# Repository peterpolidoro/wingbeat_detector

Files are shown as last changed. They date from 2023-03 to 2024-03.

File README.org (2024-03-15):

# This file is generated automatically from metadata
# File edits may be overwritten!
- Project Name: wingbeat_detector
- Synopsis: Measures fly wingbeats using IR light reflected from flapping fly wings.
- Documentation Version: 4.0.0
- Pcb Version: 4.0
- Enclosure Version: 1.1
- Supplemental BOM Version: 1.0
- Release Date: 2024-03-14
- Creation Date: 2023-02-17
- Kicad Version: 7.0.11
- License: GPL-3.0
- URL: https://github.com/peterpolidoro/wingbeat_detector
- Author: Peter Polidoro
- Email: peter@polidoro.io
- Copyright: 2024 Peter Polidoro
- References:
  - [[https://www.kicad.org/][kicad]]
  - [[https://github.com/janelia-kicad/light_sensor_boards][light_sensor_boards]]
- Papers:
  - [[https://doi.org/10.1016/j.cub.2023.01.020][Active antennal movements in Drosophila can tune wind encoding]]
  - [[https://doi.org/10.1016/j.jneumeth.2018.04.019][A novel assay to evaluate action selection in escape behavior]]
  - [[https://doi.org/10.1038/nn.4083][Cellular evidence for efference copy in Drosophila visuomotor processing]]
  - [[https://doi.org/10.1038/s41593-019-0413-4][State-dependent decoupling of sensory and motor circuits underlies behavioral flexibility in Drosophila]]
  - [[https://doi.org/10.1038/nn.2492][Active flight increases the gain of visual motion processing in Drosophila]]
  - [[https://doi.org/10.1242/jeb.82.1.377][An Optical Tachometer for Measurement of the Wing-Beat Frequency of Free-Flying Insects]]

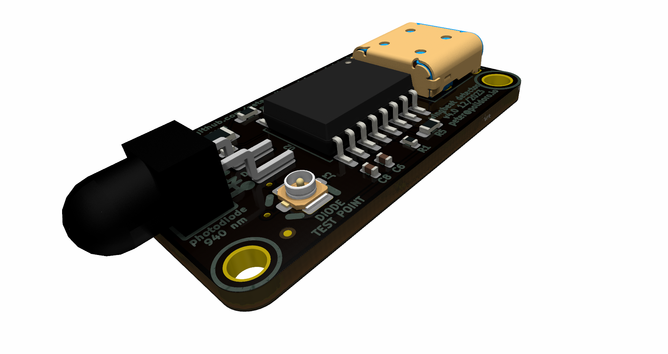
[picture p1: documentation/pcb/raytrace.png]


This wingbeat detector, or flight “tachometer”, is a small electro-optical
device that uses reflected infrared light from the fly’s wingbeats to generate
an oscillating voltage signal. The oscillation frequency of the voltage signal
matches, and thus allows one to measure, the tethered fly's wingbeat frequency.

This device is useful for plate (rather than pin) tethered flight experiments,
because with plate-glued flies, one cannot extract the wingbeat frequency via a
classical wingbeat analyzer. Microphones have also been used for extracting
wingbeat frequency, but they require a quiet room. This wingbeat detector is
immune to audible noise and only requires an infrared light source, often
already present on flight rigs for video recording.

One end of a small diameter light guide is mounted near the fly and aimed at the
wings. The other end of the light guide is in a small enclosure containing an
optical filter and printed circuit board and can be mounted off to the side of
the rig wherever there is room.

The light guide brings light reflected off of the wings down to a photodiode on
a circuit board, after passing through an optical filter to remove the unwanted
wavelengths of light. Amplifiers and filters on the circuit board convert the
tiny amounts of current from the photodiode into an oscillating voltage signal,
with a frequency range of several hundred Hertz and a magnitude range of several
Volts.

The oscillating voltage signal can be fed into a data acquisition card,
oscilloscope, and/or a speaker for recording and instant feedback on fly
wingbeat frequency. Using a threshold, the signal can be used as a simple
boolean that indicates whether the tethered animal is flying or not for
triggering experiments or synchronizing the data collection.

This device was first created at Caltech in the Dickinson lab in collaboration
with Gaby Maimon around 2010. It has transformed over several generations,
getting smaller and more robust each iteration. It has been used on rigs in
multiple universities and research institutes and has been referenced in several
papers. A couple of iterations were designed in collaboration with Sung Soo Kim
and the Card lab at Janelia Research Campus. The latest version was created in
collaboration with the Suver lab at Vanderbilt.

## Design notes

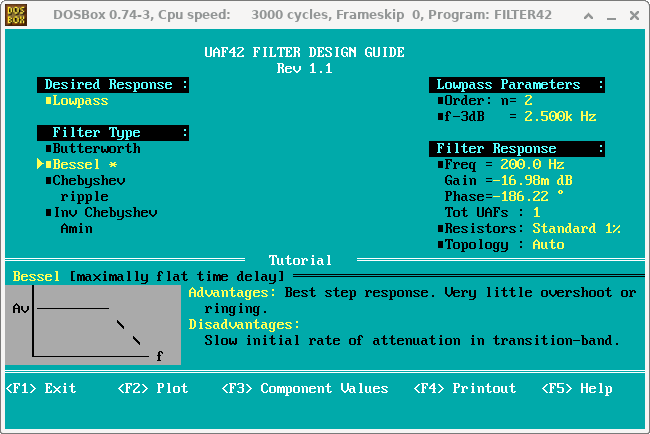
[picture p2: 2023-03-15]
documentation/filter/low-pass-filter-design.png

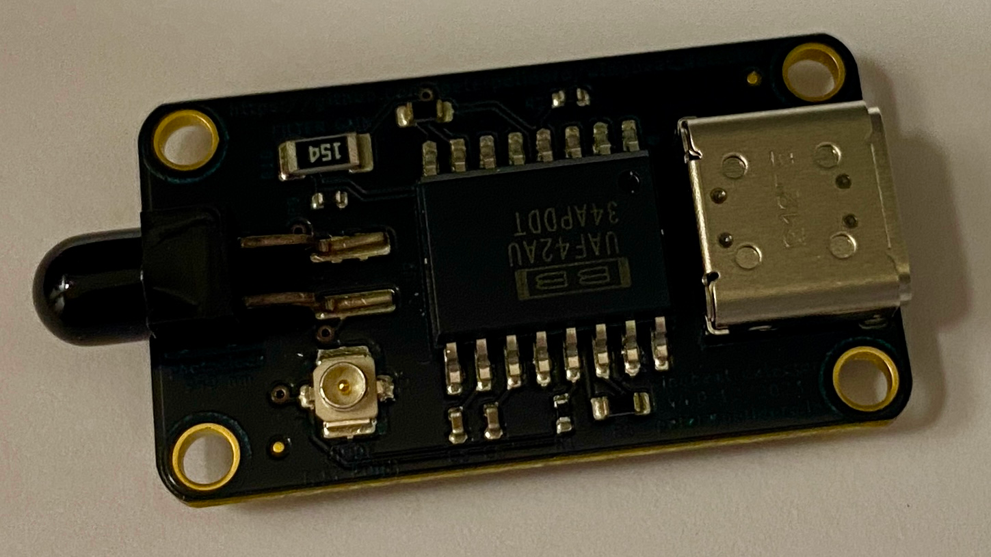
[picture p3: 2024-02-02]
documentation/photos/wingbeat_detector_photo_3.png

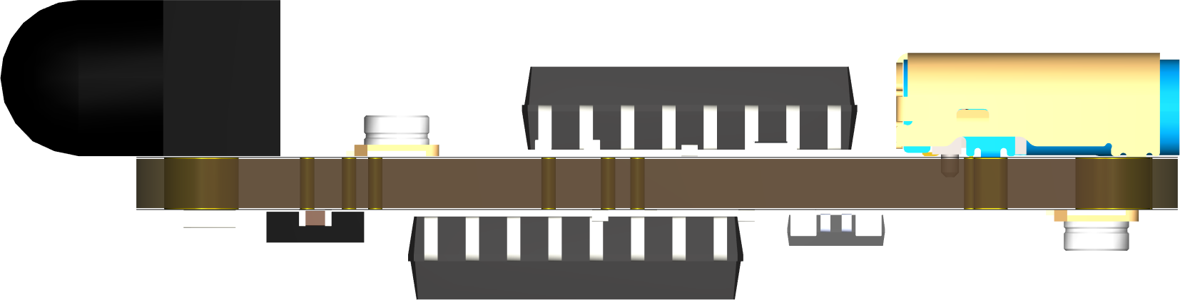
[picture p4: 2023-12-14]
documentation/pcb/front.png

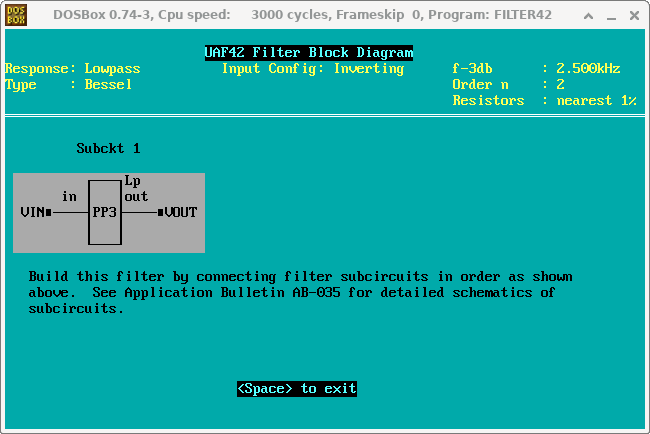
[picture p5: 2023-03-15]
documentation/filter/low-pass-filter-block-diagram.png

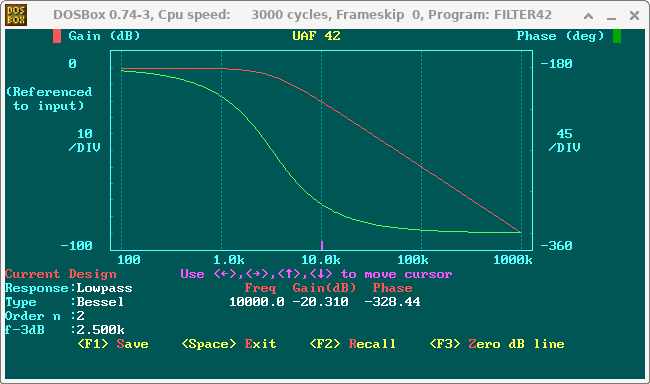
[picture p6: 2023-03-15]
documentation/filter/low-pass-filter-plot.png

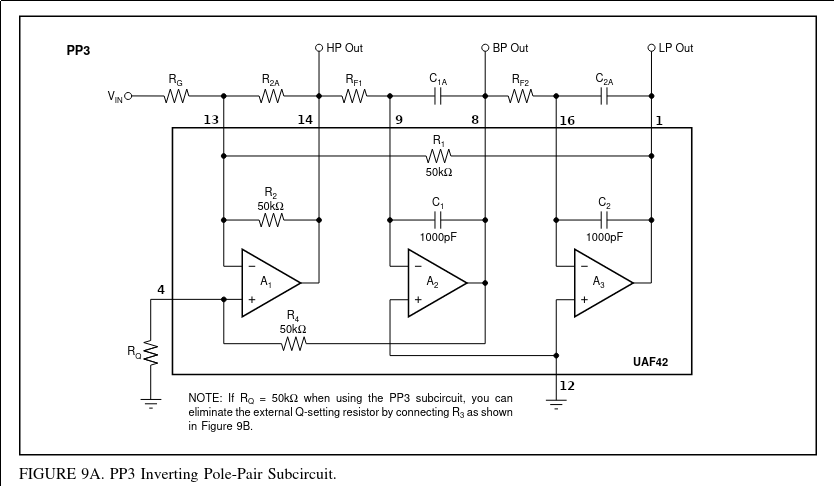
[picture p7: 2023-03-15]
documentation/filter/pp3.png

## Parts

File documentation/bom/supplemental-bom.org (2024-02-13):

#+OPTIONS: toc:nil title:nil num:nil ^:nil
#+LATEX_HEADER: \usepackage{adjustbox}
#+LATEX_HEADER: \usepackage[margin=2cm]{geometry}
* Supplemental BOM
- Project Name: wingbeat_detector
- Synopsis: Measures fly wingbeats using IR light reflected from flapping fly wings.
- Release Date: 2024-02-13
- URL: https://github.com/peterpolidoro/wingbeat_detector
- Author: Peter Polidoro
- Email: peter@polidoro.io
#+BEGIN_TABLE
#+LATEX: \adjustbox{max width=\linewidth}{
#+ATTR_LATEX: :center nil
| Item | Description                                            | Manufacturer Part Number | Manufacturer        | Quantity |   Cost |   Total |
|------+--------------------------------------------------------+--------------------------+---------------------+----------+--------+---------|
|    1 | BNC STRAIGHT BULKHEAD JACK TO AM                       | 095-850-210-150          | Amphenol RF         |        1 |  24.41 |   24.41 |
|    2 | AC/DC WALL MNT ADAPTER 5.1V 15W                        | SC0445                   | Raspberry Pi        |        1 |   8.00 |    8.00 |
|    3 | CBL ASSY BNC PLUG-PLUG RG58 5'                         | 5697-60                  | Pomona Electronics  |        1 |  21.29 |   21.29 |
|    4 | LLG 3 mm Core 420 - 2000 nm 1.2 m                      | LLG3-4Z                  | thorlabs            |        1 | 392.69 |  392.69 |
|    5 | 3 mm LLG to SM1 Adapter                                | AD3LLG                   | thorlabs            |        1 |  38.32 |   38.32 |
|    6 | Adapter External SM05 Internal SM1                     | SM1A1                    | thorlabs            |        1 |  23.41 |   23.41 |
|    7 | SM05 Adjustable Lens Tube                              | SM05V05                  | thorlabs            |        1 |  31.64 |   31.64 |
|    8 | 825nm 12.5mm Dia Longpass Filter                       | 86-062                   | edmundoptics        |        1 | 194.00 |  194.00 |
|    9 | Universal probe holder                                 | MXB                      | siskiyou            |        1 | 275.00 |  275.00 |
|   10 | MACHINE SCREW PAN PHILLIPS 2-56                        | PMSSS 256 0050 PH        | B&F Fastener Supply |        4 |   0.24 |    0.96 |
|   11 | HEX NUT 3/16" STN STEEL 2-56                           | HNSS256                  | B&F Fastener Supply |        4 |   0.28 |    1.12 |
|------+--------------------------------------------------------+--------------------------+---------------------+----------+--------+---------|
|      | Supplemental BOM Version: 1.0 |                          |                     |          |  Total | 1010.84 |
#+TBLFM: $7=$5*$6;%0.2f::@>$7=vsum(@2..@-1);%0.2f
#+LATEX: }
#+END_TABLE

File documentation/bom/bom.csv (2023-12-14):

Item | Reference(s) | Quantity | Manufacturer | Manufacturer Part Number | Vendor | Vendor Part Number | Description | Package
1 | C1 C2 C3 C4 C5 | 5 | TDK Corporation | C1608X5R1C475K080AC | Digi-Key | 445-7478-1-ND | CAP CER 4.7UF 16V X5R 0603
2 | C6 C7 C8 C9 | 4 | Yageo | CC0402ZRY5V8BB104 | Digi-Key | 311-1375-1-ND | CAP CER 0.1UF 25V Y5V | 0402
3 | C10 | 1 | Samsung Electro-Mechanics | CL05A105KL5NRNC | Digi-Key | 1276-6796-1-ND | CAP CER 1UF 35V X5R | 0402
4 | C11 | 1 | KEMET | C0402C300J5GACAUTO | Digi-Key | 399-C0402C300J5GACAUTOCT-ND | CAP CER 30PF 50V C0G/NP0 | 0402
5 | D1 | 1 | American Bright Optoelectronics Corporation | BPD-BQDA38V-FZ04 | Digi-Key | BPD-BQDA38V-FZ04CT-ND | SENSOR PHOTODIODE RADIAL
6 | J1 | 1 | Amphenol | 10137062-00021LF | Digi-Key | 609-6109-1-ND | CONN RCP USB3.1 TYPEC 24P SMD RA
7 | J2 J3 | 2 | Amphenol RF | A-1JB | Digi-Key | 115-A-1JBCT-ND | CONN UMC JACK STR 50 OHM SMD
8 | R1 R3 R6 R8 | 4 | Panasonic Electronic Components | ERJ-2RKF4992X | Digi-Key | P49.9KLCT-ND | RES SMD 49.9K OHM 1% 1/10W | 0402
9 | R2 R4 | 2 | Panasonic Electronic Components | ERJ-2RKF6812X | Digi-Key | P68.1KLCT-ND | RES SMD 68.1K OHM 1% 1/10W | 0402
10 | R5 R7 | 2 | Vishay Dale | CRCW06033M65FKEA | Digi-Key | 541-3.65MHCT-ND | RES SMD 3.65M OHM 1% 1/10W | 0603
11 | R9 | 1 | Panasonic Electronic Components | ERJ-2RKF2490X | Digi-Key | P249LCT-ND | RES SMD 249 OHM 1% 1/10W | 0402
12 | R10 | 1 | Panasonic Electronic Components | ERA-8AEB154V | Digi-Key | P150KBCCT-ND | RES SMD 150K OHM 0.1% 1/4W | 1206
13 | R11 | 1 | Panasonic Electronic Components | ERJ-PM8F2004V | Digi-Key | 10-ERJ-PM8F2004VCT-ND | RES 2.0M OHM 1% 0.66W | 1206
14 | U1 | 1 | Maxim Integrated | MAX865EUA+ | Digi-Key | MAX865EUA+-ND | IC REG CHARGE PUMP INV DL 8UMAX | SOP65P490X110-8N
15 | U2 U3 | 2 | Texas Instruments | UAF42AU | Digi-Key | UAF42AU-ND | IC UNIV ACTIVE FILTER 16-SOIC
16 | U4 | 1 | Texas Instruments | OPA381AIDRBT | Digi-Key | 296-17363-1-ND | IC TRANSIMPEDANCE 1 CIRCUIT 8SON

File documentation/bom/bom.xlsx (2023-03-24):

Item | Reference(s) | Quantity | Manufacturer | Manufacturer Part Number | Vendor | Vendor Part Number | Description | Package
1 | C1 C2 C3 C4 C5 C13 | 6 | TDK Corporation | C1608X5R1C475K080AC | Digi-Key | 445-7478-1-ND | CAP CER 4.7UF 16V X5R 0603
2 | C6 C7 C8 C9 C10 C12 | 6 | Yageo | CC0402ZRY5V8BB104 | Digi-Key | 311-1375-1-ND | CAP CER 0.1UF 25V Y5V | 402
3 | C11 | 1 | TDK Corporation | CGA2B2C0G1H020C050BA | Digi-Key | 445-5572-1-ND | CAP CER 2PF 50V C0G | 402
4 | D1 | 1 | American Bright Optoelectronics Corporation | BPD-BQDA38V-FZ04 | Digi-Key | BPD-BQDA38V-FZ04CT-ND | SENSOR PHOTODIODE RADIAL
5 | D2 | 1 | American Bright Optoelectronics Corporation | BIR-BM17J8V-FZ04 | Digi-Key | BIR-BM17J8V-FZ04CT-ND | 5MM 940 IR
6 | J1 | 1 | Amphenol | 10137062-00021LF | Digi-Key | 609-6109-1-ND | CONN RCP USB3.1 TYPEC 24P SMD RA
7 | J2 J3 J4 | 3 | Amphenol RF | A-1JB | Digi-Key | 115-A-1JBCT-ND | CONN UMC JACK STR 50 OHM SMD
8 | Q1 | 1 | Texas Instruments | CSD17483F4 | Digi-Key | 296-38914-1-ND | MOSFET N-CH 30V 1.5A 3PICOSTAR
9 | R1 R3 R6 R8 R10 R11 R12 R14 R16 | 9 | Panasonic Electronic Components | ERJ-2RKF4992X | Digi-Key | P49.9KLCT-ND | RES SMD 49.9K OHM 1% 1/10W | 402
10 | R2 R4 | 2 | Panasonic Electronic Components | ERJ-2RKF6812X | Digi-Key | P68.1KLCT-ND | RES SMD 68.1K OHM 1% 1/10W | 402
11 | R5 R7 | 2 | Vishay Dale | CRCW06033M65FKEA | Digi-Key | 541-3.65MHCT-ND | RES SMD 3.65M OHM 1% 1/10W | 603
12 | R9 | 1 | Panasonic Electronic Components | ERJ-2RKF2490X | Digi-Key | P249LCT-ND | RES SMD 249 OHM 1% 1/10W | 402
13 | R13 R15 | 2 | Panasonic Electronic Components | ERJ-2RKF2322X | Digi-Key | P23.2KLCT-ND | RES SMD 23.2K OHM 1% 1/10W | 402
14 | R17 | 1 | Panasonic Electronic Components | ERJ-2RKF2001X | Digi-Key | P2.00KLCT-ND | RES SMD 2K OHM 1% 1/10W | 402
15 | RV1 RV2 | 2 | Bourns Inc. | 3223W-1-504E | Digi-Key | 3223W-1-504ECT-ND | TRIMMER 500K OHM 0.125W J LEAD
16 | U1 | 1 | Maxim Integrated | MAX865EUA+ | Digi-Key | MAX865EUA+-ND | IC REG CHARGE PUMP INV DL 8UMAX | SOP65P490X110-8N
17 | U2 U3 | 2 | Texas Instruments | UAF42AU | Digi-Key | UAF42AU-ND | IC UNIV ACTIVE FILTER 16-SOIC
18 | U4 | 1 | Texas Instruments | OPA381AIDRBT | Digi-Key | 296-17363-1-ND | IC TRANSIMPEDANCE 1 CIRCUIT 8SON
19 | U5 | 1 | STMicroelectronics | TSV630IQ1T | Digi-Key | 497-17045-1-ND | IC OPAMP GP 1 CIRCUIT | 6DFN
20 | U6 | 1 | American Bright Optoelectronics Corporation | AB-EZPC-10 | Digi-Key | AB-EZPC-10CT-ND | IC LED DRIVER LINEAR 50MA | 6DFN

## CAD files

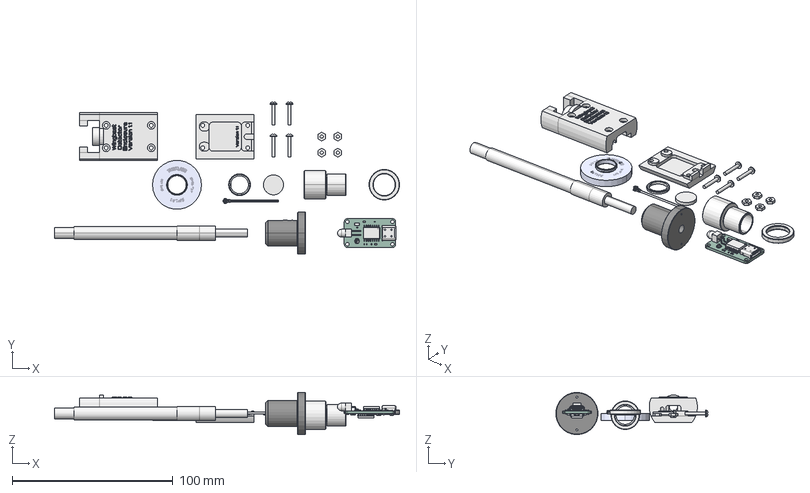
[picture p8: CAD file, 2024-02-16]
documentation/3dmodels/freecad/documentation.FCStd
214.6 x 94.6 x 26.3 mm
wingbeat_detector PCB
enclosure-top001
enclosure-bottom001
screw001
screw002
screw003
screw004
nut001
nut002
nut003
nut004
tube001
tube-nut001
lens-nut
ֱ2_86062
1691-E0W

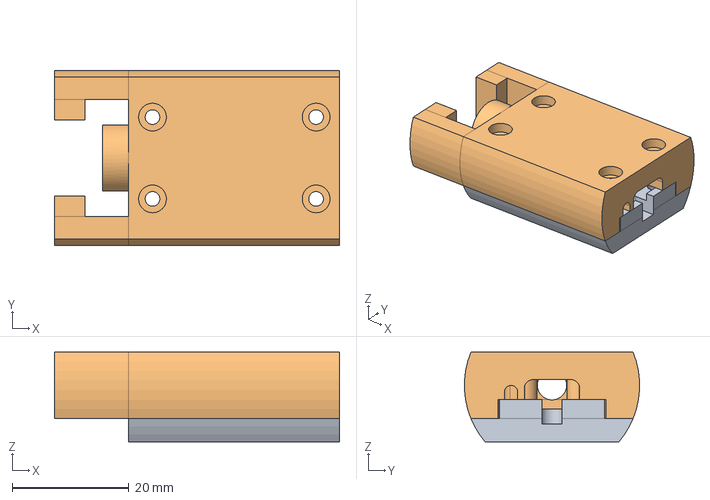
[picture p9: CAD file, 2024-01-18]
documentation/3dmodels/freecad/wingbeat_detector.FCStd
48.8 x 30.0 x 15.3 mm
enclosure-bottom001
enclosure-top001

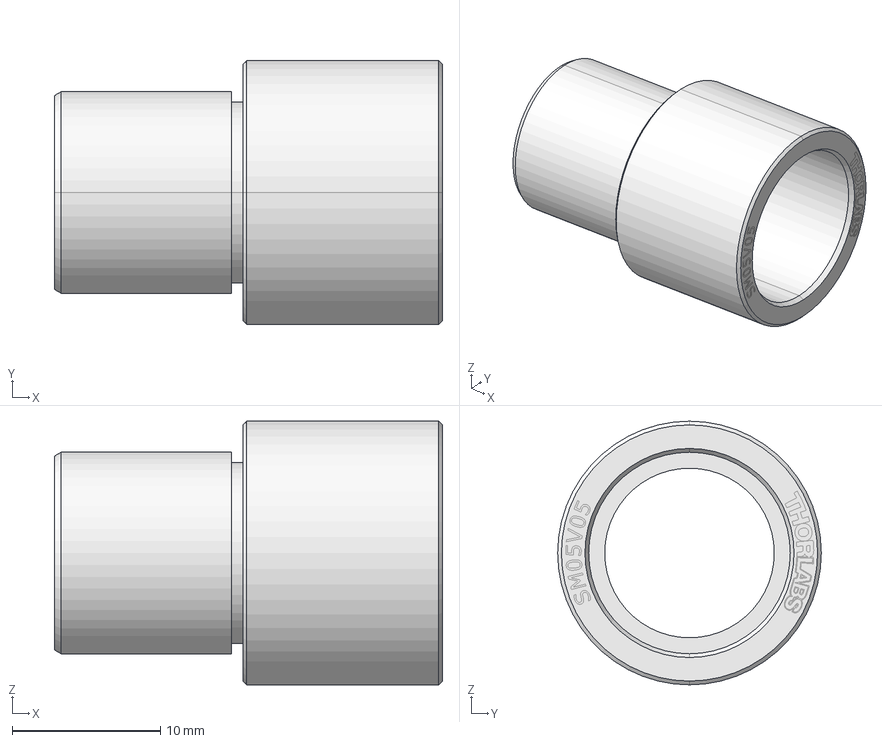
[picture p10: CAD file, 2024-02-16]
documentation/3dmodels/step/tube.step
26.2 x 17.8 x 17.8 mm

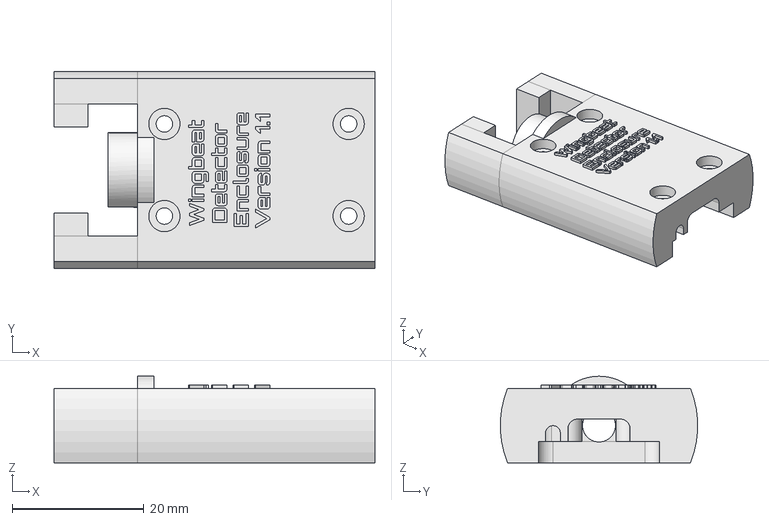
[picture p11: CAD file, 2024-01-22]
documentation/3dmodels/step/wingbeat-detector-enclosure-top.step
48.8 x 30.0 x 13.2 mm

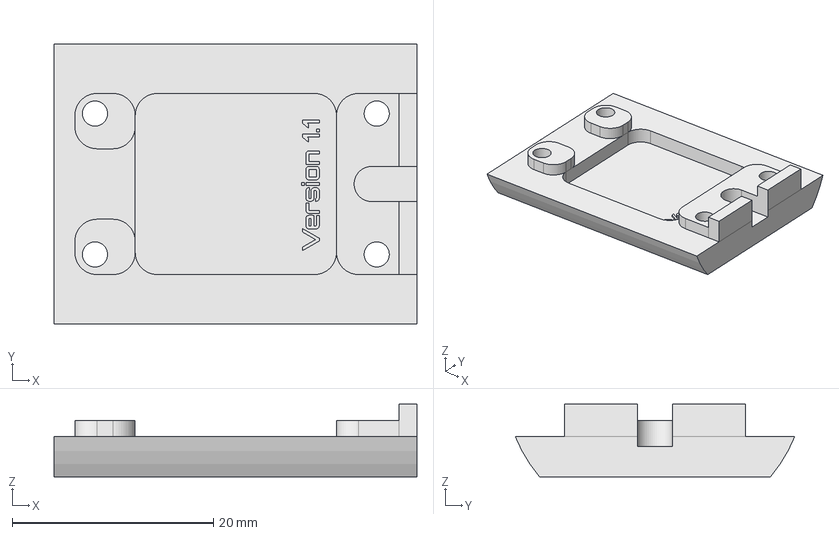
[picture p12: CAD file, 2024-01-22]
documentation/3dmodels/step/wingbeat-detector-enclosure-bottom.step
36.1 x 27.8 x 7.21 mm

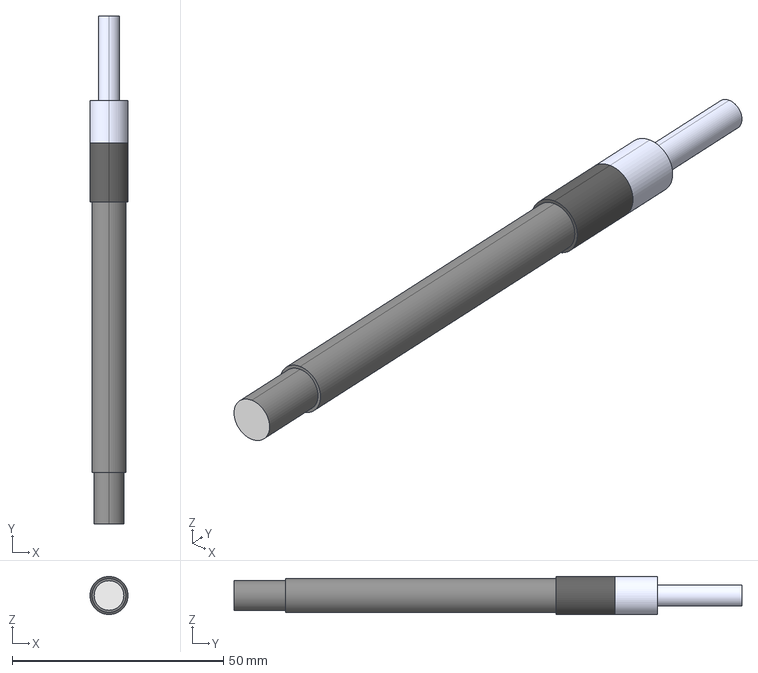
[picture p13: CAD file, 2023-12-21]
documentation/3dmodels/step/LLG-trimmed.step
9.00 x 120.2 x 9.00 mm

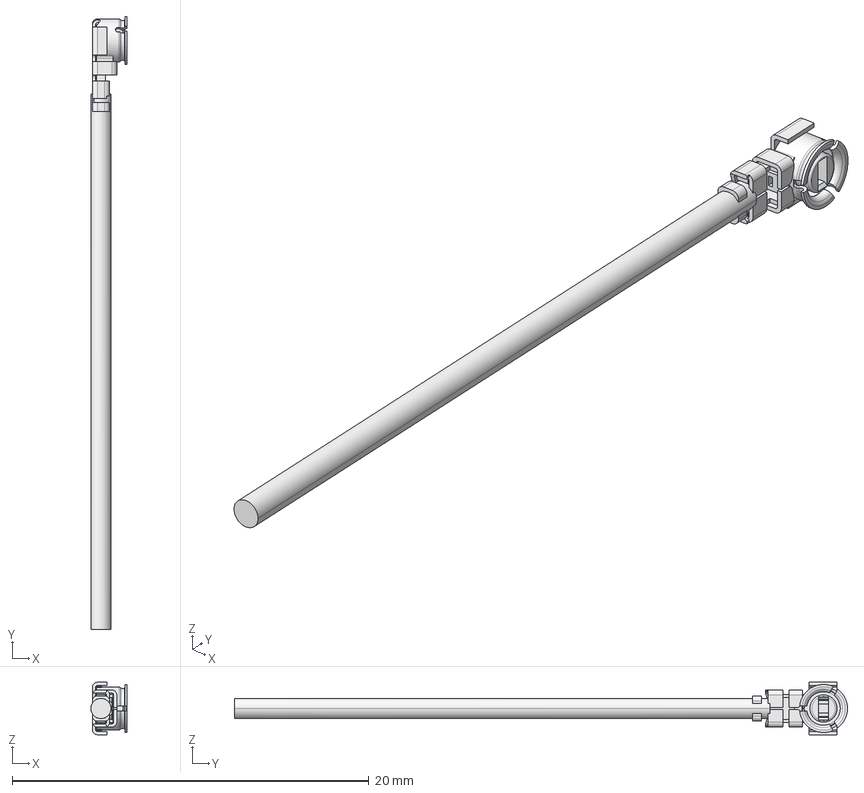
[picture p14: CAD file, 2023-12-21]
documentation/3dmodels/step/AMC-plug.step
2.03 x 34.4 x 2.95 mm

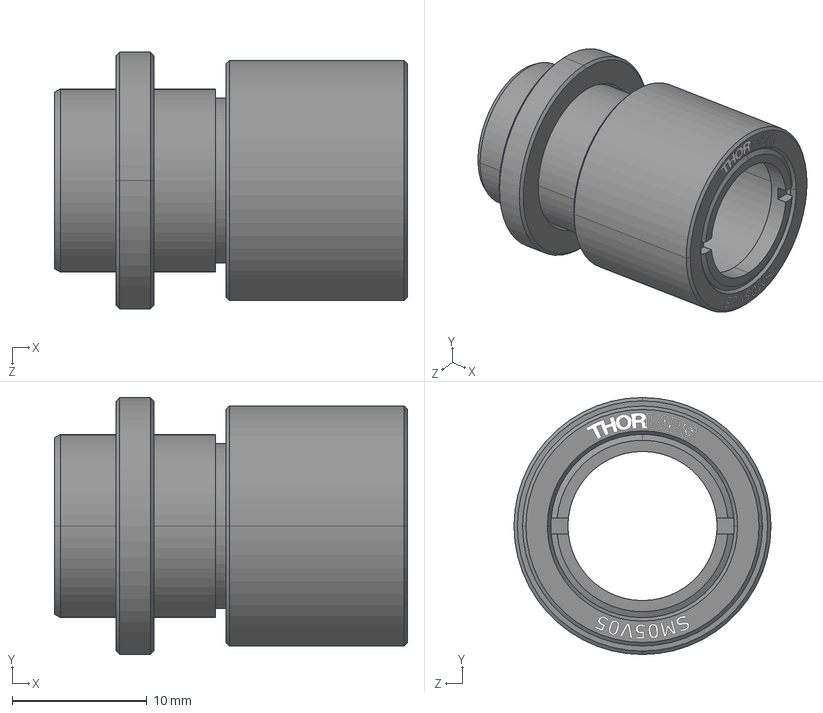
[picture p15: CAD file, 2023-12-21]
documentation/3dmodels/step/SM05V05.step
26.2 x 19.1 x 19.1 mm

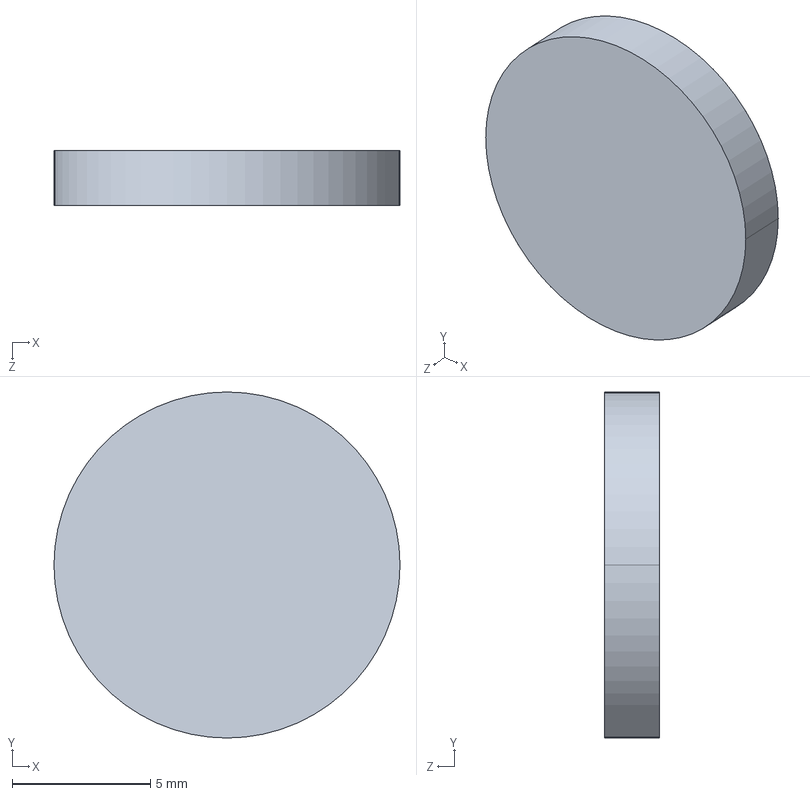
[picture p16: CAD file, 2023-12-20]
documentation/3dmodels/step/filter.step
12.5 x 12.5 x 2.00 mm

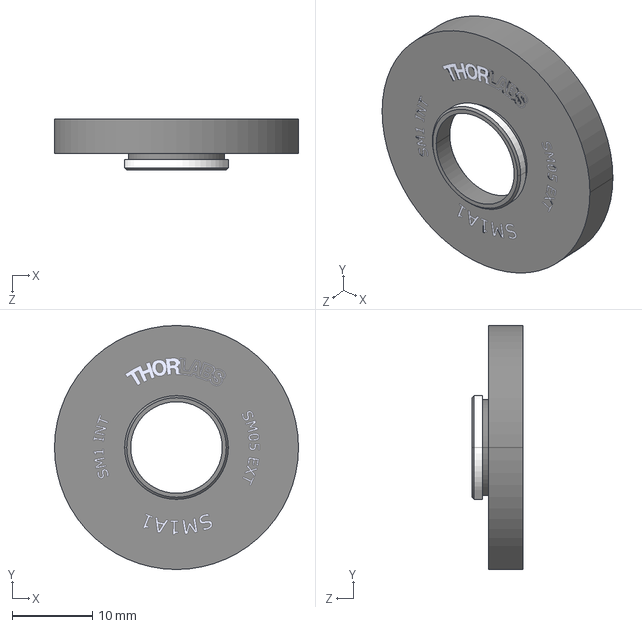
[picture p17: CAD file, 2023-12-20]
documentation/3dmodels/step/SM1A1.step
30.5 x 30.5 x 6.35 mm

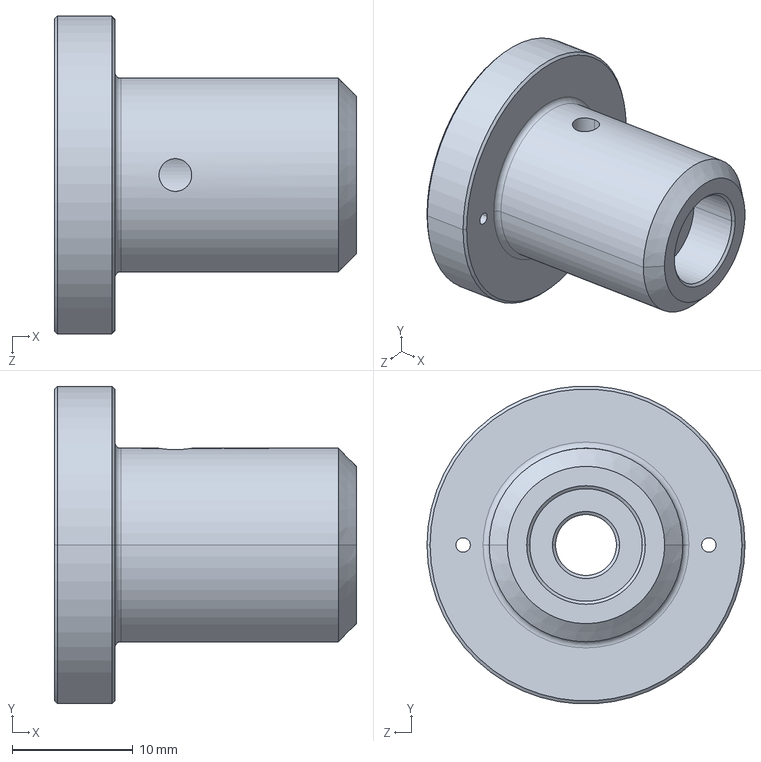
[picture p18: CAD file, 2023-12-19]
documentation/3dmodels/step/AD3LLG.step
25.0 x 26.2 x 26.3 mm

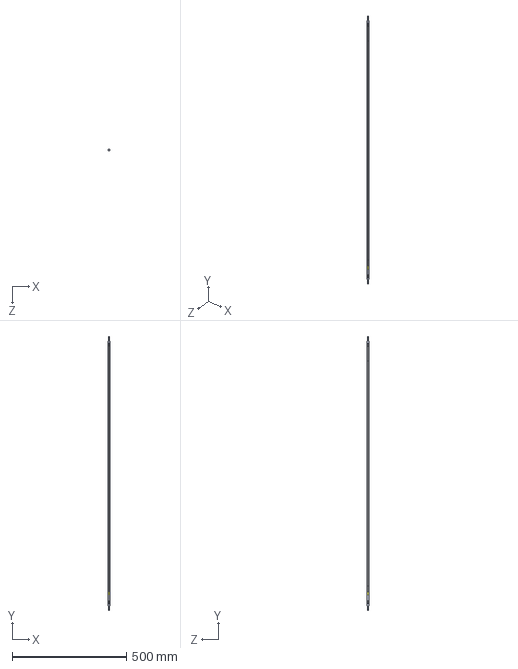
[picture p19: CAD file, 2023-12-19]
documentation/3dmodels/step/LLG3-4Z.step
9.00 x 1200.0 x 9.00 mm

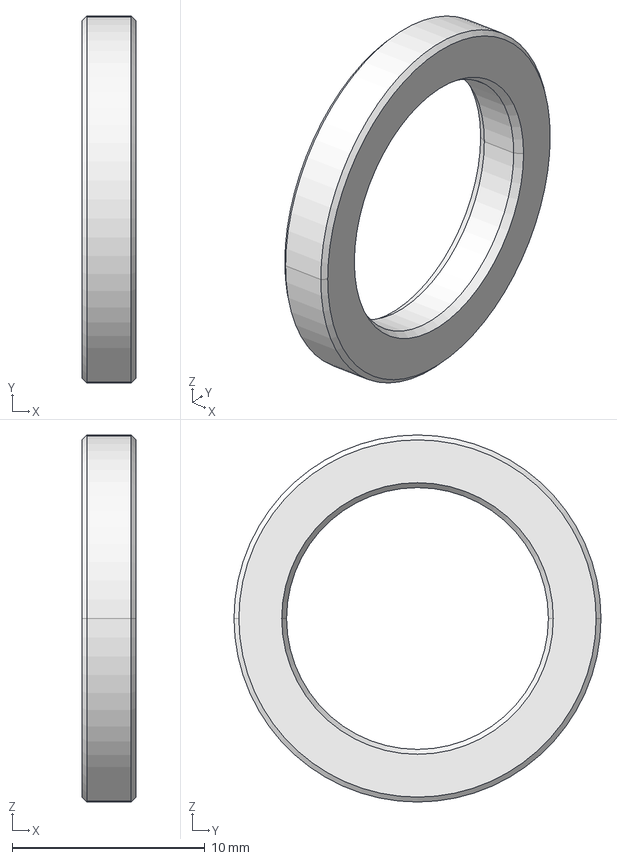
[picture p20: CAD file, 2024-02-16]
documentation/3dmodels/step/tube-nut.step
2.79 x 19.1 x 19.1 mm

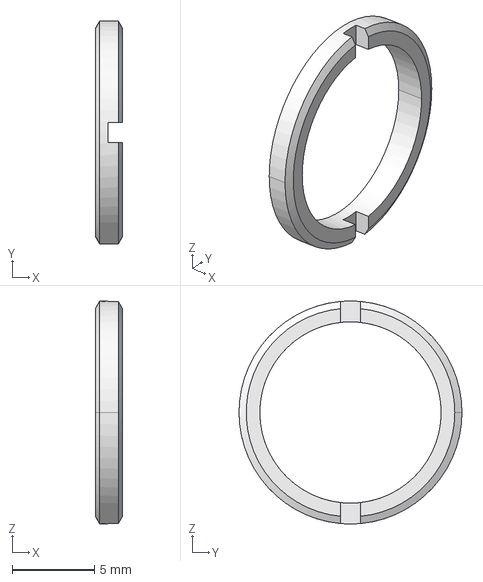
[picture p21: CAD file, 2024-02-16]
documentation/3dmodels/step/tube-lens-nut.step
1.65 x 13.6 x 13.6 mm

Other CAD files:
documentation/3dmodels/step/nut.step
documentation/3dmodels/step/screw.step

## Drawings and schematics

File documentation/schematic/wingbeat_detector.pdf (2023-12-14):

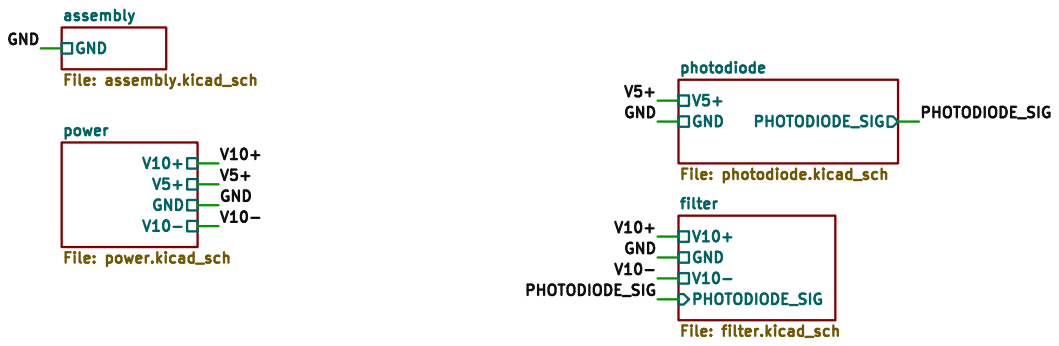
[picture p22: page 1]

assembly File: assembly.kicad_sch GND

V5+ V10+ V10- power File: power.kicad_schGND GND

photodiode File: photodiode.kicad_sch GND

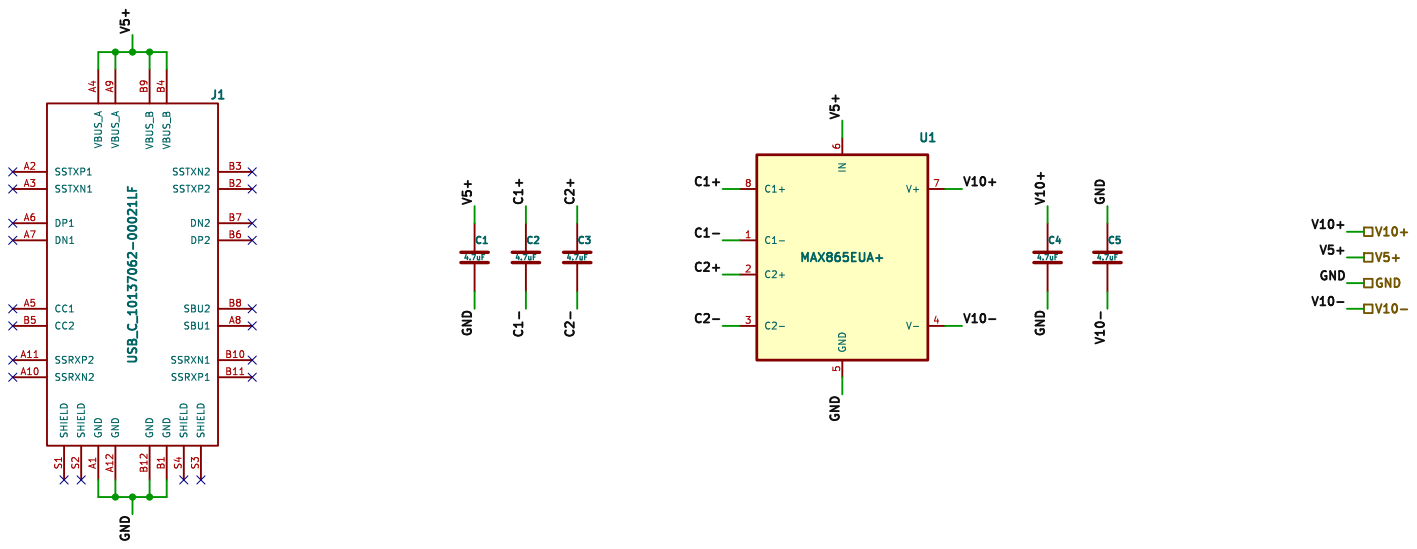
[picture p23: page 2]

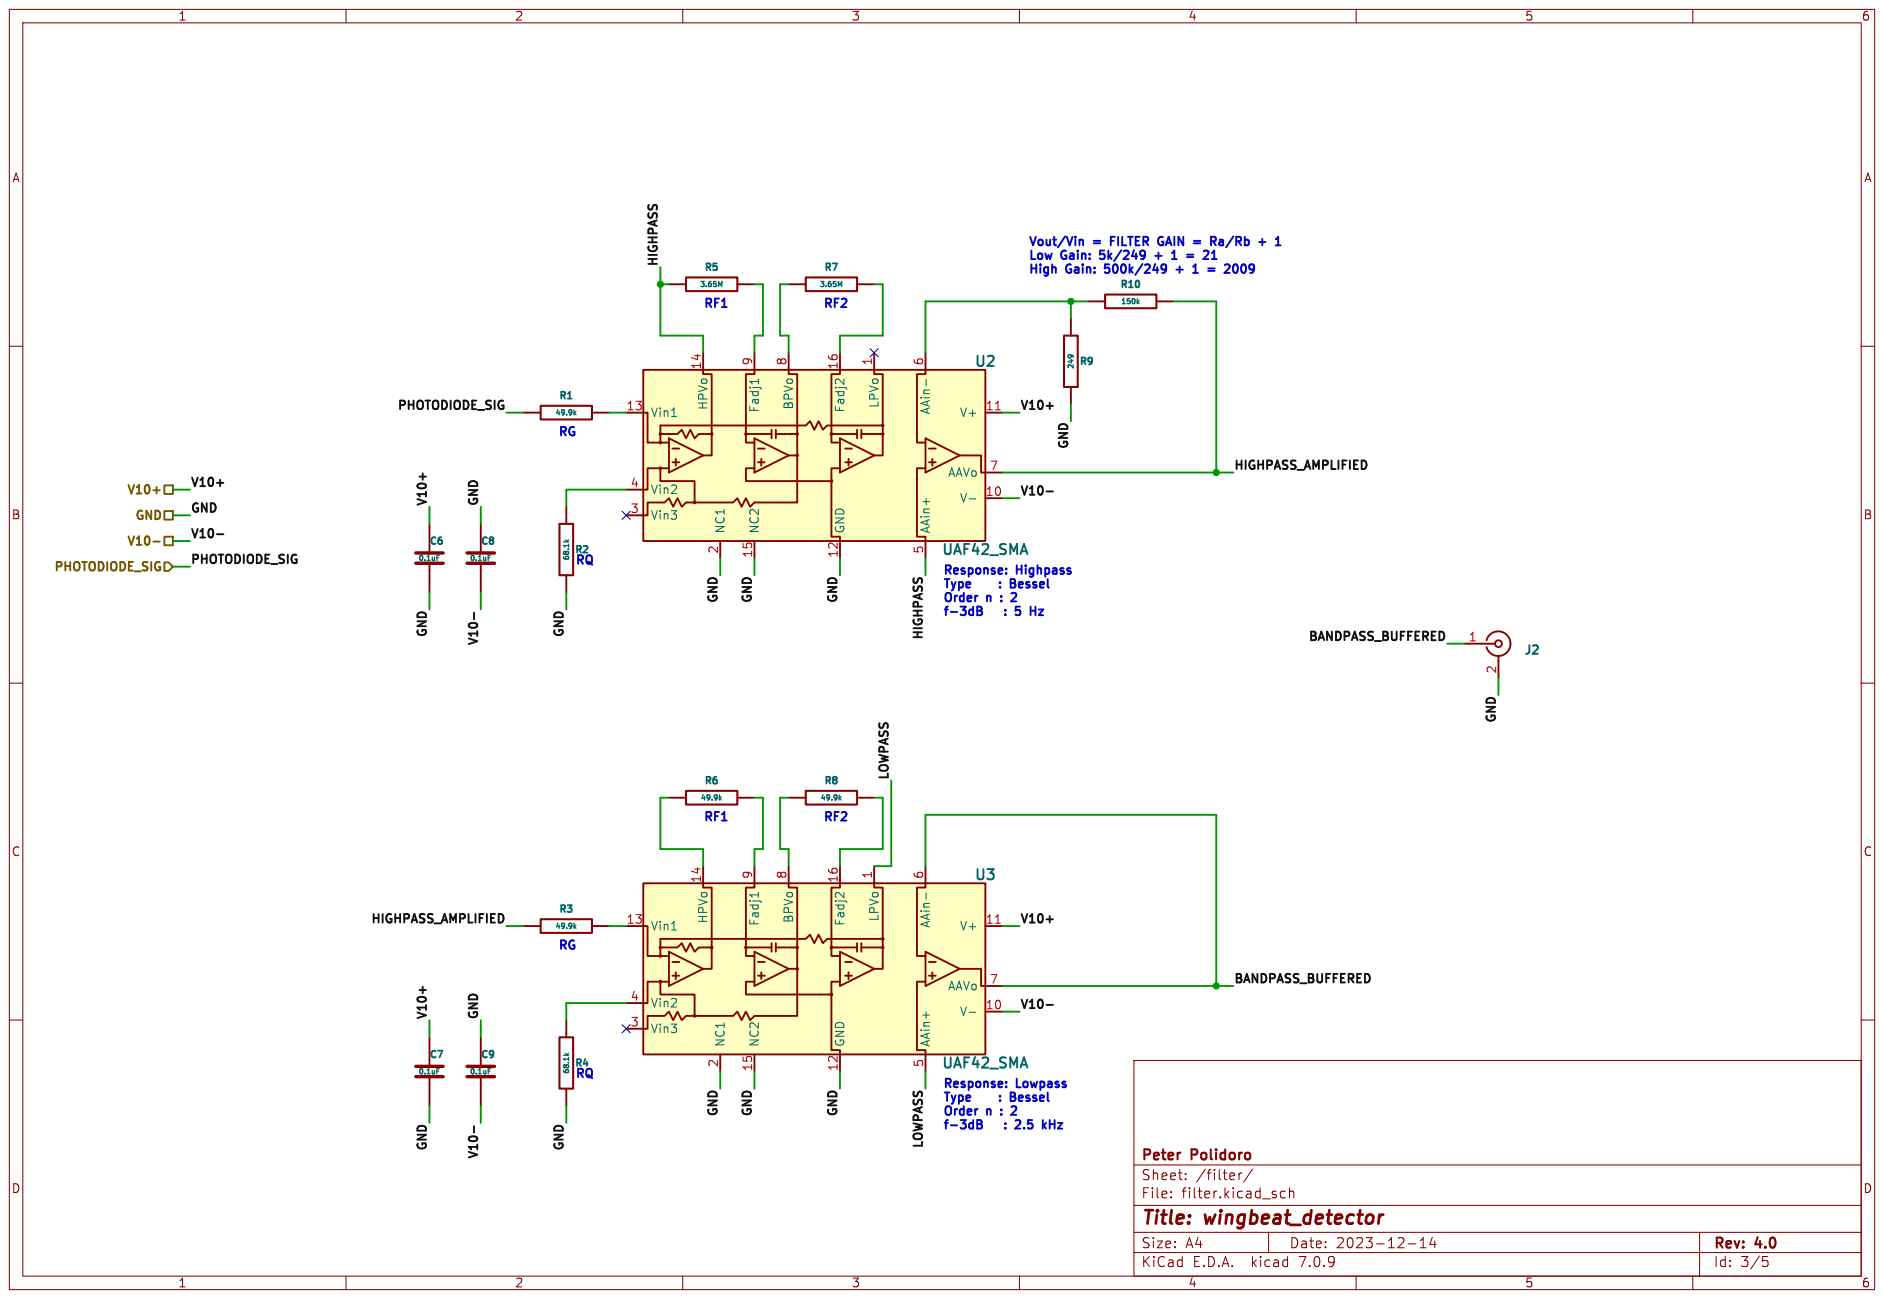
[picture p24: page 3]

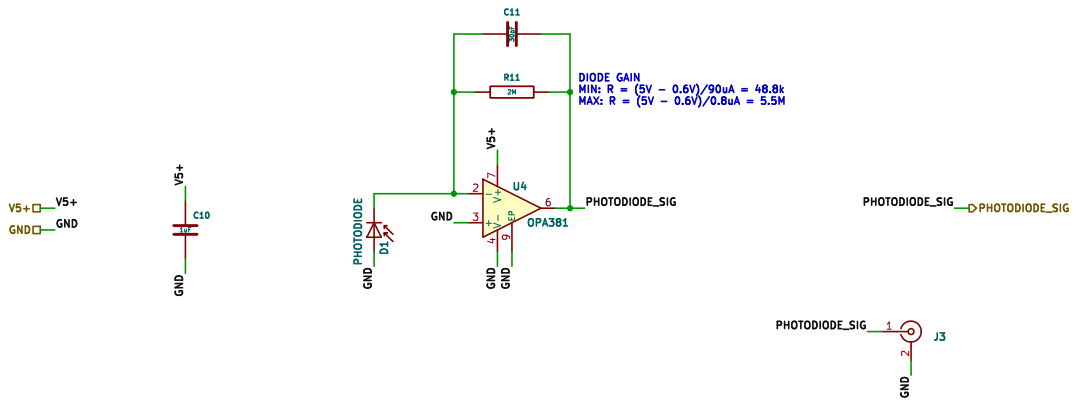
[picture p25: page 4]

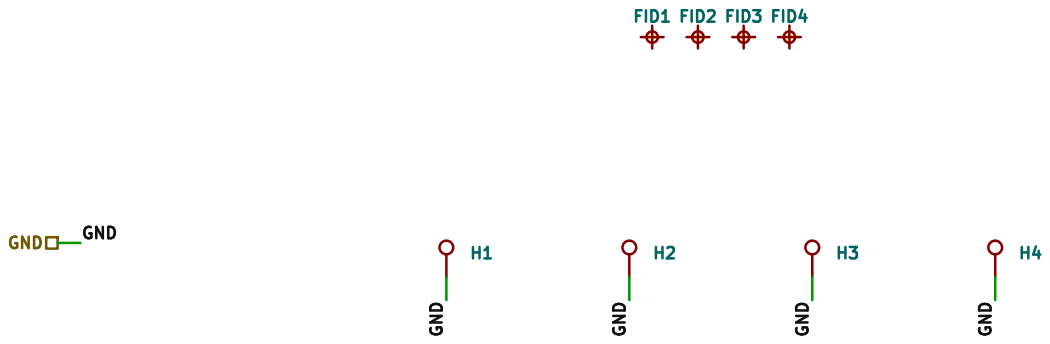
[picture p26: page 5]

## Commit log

2022-11-18 Add KiCad project
    [light_sensor_opt101.kicad_pcb, light_sensor_opt101.kicad_sch]
2023-02-17 Rename to wingbeat_detector
    [wingbeat_detector.kicad_pcb, wingbeat_detector.kicad_sch]
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2023-02-22 Update to kicad 7.0
    [wingbeat_detector.kicad_pcb, wingbeat_detector.kicad_sch]
2023-02-23 Add symbols and documentation
    [wingbeat_detector.kicad_sch]
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2023-02-27 Add documentation and initial schematic part
    [wingbeat_detector.kicad_sch]
2023-02-28 Add connectors and UAF42
    [wingbeat_detector.kicad_pcb, wingbeat_detector.kicad_sch]
2023-02-28 Switch from SMA to UNC
    [wingbeat_detector.kicad_pcb, wingbeat_detector.kicad_sch]
2023-03-02 Add OPT101 socket
    [wingbeat_detector.kicad_pcb]
2023-03-02 Add MAX865
    [wingbeat_detector.kicad_pcb, wingbeat_detector.kicad_sch]
2023-03-02 Rounded board edge corners
    [wingbeat_detector.kicad_pcb]
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2023-03-07 Remove OPT101 and replace
    [wingbeat_detector.kicad_pcb, wingbeat_detector.kicad_sch]
2023-03-08 Add sheets
    [connectors.kicad_sch, filter.kicad_sch, led.kicad_sch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]
2023-03-09 Add led driver
    [connectors.kicad_sch, led.kicad_sch, power.kicad_sch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]
2023-03-10 Add mosfet and opa381
    [connectors.kicad_sch, filter.kicad_sch, led.kicad_sch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]
2023-03-13 Remove connectors schematic sheet
    [connectors.kicad_sch, filter.kicad_sch, led.kicad_sch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]
2023-03-13 Rearrange mounting holes
    [wingbeat_detector.kicad_sch]
2023-03-14 Add buffered output
    [assembly.kicad_sch, filter.kicad_sch, led.kicad_sch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]
2023-03-15 Initial schematic layout
    [filter.kicad_sch, led.kicad_sch, photodiode.kicad_sch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]
2023-03-16 Double check schematic
    [filter.kicad_sch, led.kicad_sch, photodiode.kicad_sch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]
2023-03-16 Update courtyard for footprints
    [wingbeat_detector.kicad_pcb]
2023-03-17 Rearrange pcb footprints
    [assembly.kicad_sch, filter.kicad_sch, led.kicad_sch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]
2023-03-17 Initial pcb component layout
    [wingbeat_detector.kicad_pcb]
2023-03-17 Move components after trying to route
    [wingbeat_detector.kicad_pcb]
2023-03-20 Move footprints and add some tracks
    [wingbeat_detector.kicad_pcb]
2023-03-20 Add more tracks
    [wingbeat_detector.kicad_pcb]
2023-03-21 Finished routing tracks with no errors
    [led.kicad_sch, wingbeat_detector.kicad_pcb]
2023-03-21 Fill zones, no errors
    [wingbeat_detector.kicad_pcb]
2023-03-21 Adjust silkscreen text
    [assembly.kicad_sch, filter.kicad_sch, led.kicad_sch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]
2023-03-22 Copy edge cuts to documentation layers
    [assembly.kicad_sch, filter.kicad_sch, led.kicad_sch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]
2023-03-23 Finished layout for v3.0
    [assembly.kicad_sch, filter.kicad_sch, led.kicad_sch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]
2023-03-23 Update documentation
    [wingbeat_detector.kicad_pcb]
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2023-03-23 Update LED driver 3D model
    [wingbeat_detector.kicad_pcb]
2023-03-24 Add documentation
    [wingbeat_detector-B_Cu.gbl, wingbeat_detector-B_Fab.gbr, wingbeat_detector-B_Mask.gbs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]
2023-03-24 Update bom
    [assembly.kicad_sch, bom.csv, bom.xlsx]
2023-03-24 Add pcb images:
    [wingbeat_detector.kicad_pcb]
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2023-03-29 Modify after submitting for manufacturing review
    [assembly.kicad_sch, filter.kicad_sch, led.kicad_sch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]
2023-03-30 Add vendor parts list
    [Digi-Key_parts.csv]
2023-03-31 Increase pad size for minimum paste aperture of 13 mil (0.3302mm).
    [assembly.kicad_sch, filter.kicad_sch, led.kicad_sch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]
2023-08-03 packages3D -> 3dmodels
    [wingbeat_detector.kicad_pcb]
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2023-10-05 Remove LED
    [assembly.kicad_sch, filter.kicad_sch, photodiode.kicad_sch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]
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2023-12-08 More progress towards v4
    [assembly.kicad_sch, filter.kicad_sch, photodiode.kicad_sch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]
2023-12-11 First attempt at routing
    [assembly.kicad_sch, filter.kicad_sch, photodiode.kicad_sch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]
2023-12-12 Adjust tracks and zones
    [assembly.kicad_sch, filter.kicad_sch, photodiode.kicad_sch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]
2023-12-13 Rearrange parts
    [assembly.kicad_sch, filter.kicad_sch, photodiode.kicad_sch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]
2023-12-14 Update images and documentation
    [Digi-Key_parts.csv, assembly.kicad_sch, bom.csv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]
2023-12-14 Remove led schematic
    [led.kicad_sch]
2023-12-15 Change columns for manufacturer and manufacturer part number
    [filter.kicad_sch, photodiode.kicad_sch, power.kicad_sch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]
2023-12-19 Add some assembly components
    [AD3LLG.step, LLG3-4Z.step, llg.FCStd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]
2023-12-20 Add assembly parts
    [SM05L05.step, SM1A1.step, filter.step]
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2023-12-21 Switch to adjustable lens tube
    [SM05L05.step, SM05V05.step, llg.FCStd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]
2023-12-21 Initial freecad assembly
    [AMC-plug.step, LLG-trimmed.step, wingbeat_detector.FCStd]
2023-12-21 Update freecad file
    [wingbeat_detector.FCStd]
2023-12-22 Update model
    [wingbeat_detector.FCStd]
2024-01-02 Progress towards enclosure-top
    [wingbeat_detector.FCStd]
2024-01-04 Modify enclosure
    [wingbeat_detector.FCStd]
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2024-01-11 Updates to enclosure bottom
    [wingbeat_detector.FCStd]
2024-01-12 Finish enclosure and add step files
    [wingbeat-detector-enclosure-bottom.step, wingbeat-detector-enclosure-top.step, wingbeat_detector.FCStd]
2024-01-18 Resize enclosure after printing
    [wingbeat_detector.FCStd]
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2024-02-15 Add some FreeCAD files
    [documentation.FCStd, nut.step, screw.step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]
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2024-02-16 Progress towards assembly images
    [documentation.FCStd, tube-lens-nut.step, tube-nut.step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]
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
